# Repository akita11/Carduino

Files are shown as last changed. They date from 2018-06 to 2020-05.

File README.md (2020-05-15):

# Carduino

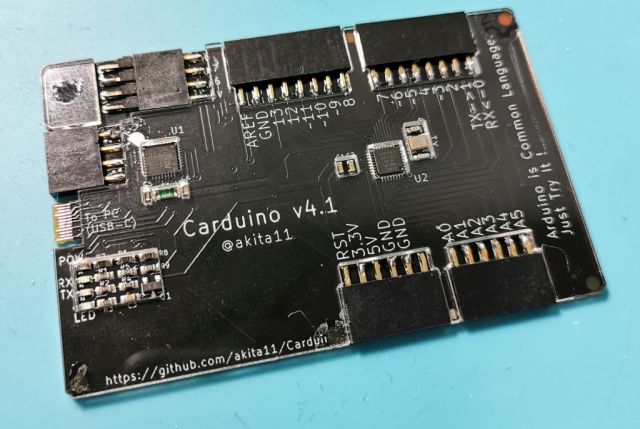
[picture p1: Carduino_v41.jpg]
omote


Carduino (v4.1)は、クレジットカードサイズ・厚さ2.4mmの、ArduinoUNO互換機です。
財布などにいつもいれておいて、いつでもその場でArduinoを使うことができます。
「Arduinoは興味あるんだけど、まだ触ったことないんだよね」という人に会ったら、その場でArduinoを体験してもらいましょう。
* ArduinoIDEの導入からLチカまでの手順は、本体裏面にシルクで書かれています。またArduinoIDEのダウンロード先もQRコードで読み取れます。
* USB-Aコネクタ（収納式）で、PCのUSB端子に直接差し込むことができます。またUSB Type-Cケーブルで接続することもできます。
* Arduinoの入出力端子はメスソケットですので、ジャンパワイヤ等をさしてつかうこともできます。
* USB-シリアル変換には、FTDI FT232Rを使っています。
* [スイッチサイエンスで委託販売はじまりました](https://www.switch-science.com/catalog/6368/)

# 使い方

本体裏面のシルクを参照してください。

PCとの接続は、以下の2通りが可能です。
* 本体のコネクタをいったんはずし、以下のようにとりつけ、PCのUSBポートに直接さしこみます。（※コネクタの向きに注意してください。収納時とは表裏を逆にさして使用します。表裏を逆で使用すると、本体やPCを破損する恐れがあります）

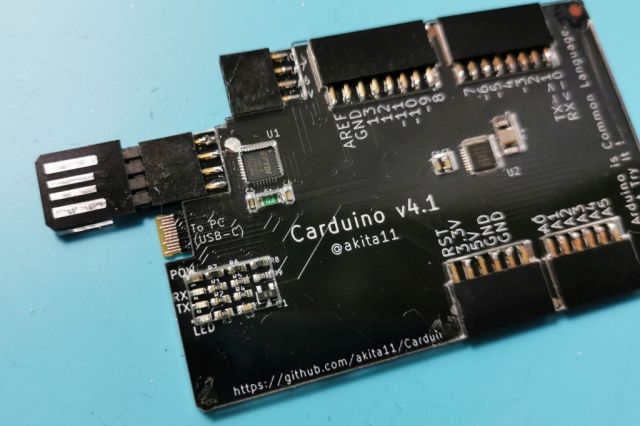
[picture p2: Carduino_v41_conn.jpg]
USB connector


* USB Type-Cケーブルを本体コネクタ部にさしこみます。

なお未使用時にUSBコネクタ部を格納しておくコネクタには、A6/A7、電源5V、GNDがつながっています。

# 作り方

* ガーバーデータ(Carduino_v41_gerber.zip)で基板製造（板厚0.6mm）し、部品表（Carduino_v41_bom.xlsx）の部品をとりつけます。
* 4p、6p、8pのピンソケット（各2個：秋月電子等で購入できます）を、基板の溝にあわせて横向けにはんだ付けします。また4pピンヘッダ（秋月電子等で購入できます）をUSBコネクタ側にとりつけます。
* 板厚1mmまたは1.5mmのアクリル板をCarduino_v41_cover.pdfでレーザーカッター等でカットし、本体に透明両面テープや透明ボンド等で固定します。
* ArduinoUNO用のブートローダを書き込みます

# 作者

Junichi Akita (akita@ifdl.jp, @akita11)

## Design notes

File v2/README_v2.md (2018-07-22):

# Carduino

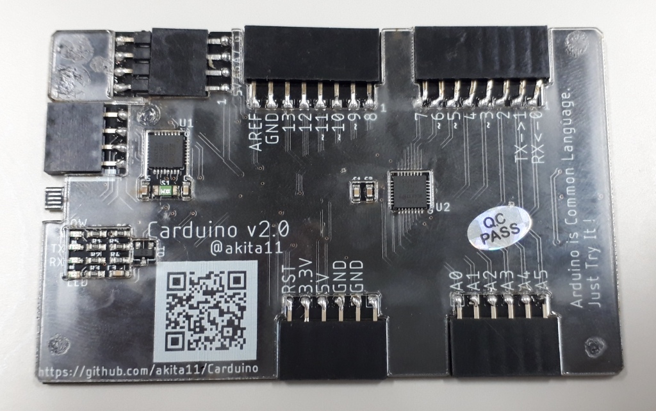
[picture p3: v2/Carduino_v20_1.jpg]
omote


Carduinoは、クレジットカードサイズ・厚さ2.4mmの、Arduino互換機(ArduinoProMini/8MHz)です。
財布などにいつもいれておいて、いつでもその場でArduinoを使うことができます。
「Arduinoは興味あるんだけど、まだ触ったことないんだよね」という人に会ったら、その場でArduinoを体験してもらいましょう。
* ArduinoIDEの導入からLチカまでの手順は、本体裏面にシルクで書かれています。またArduinoIDEのダウンロード先もQRコードで読み取れます。
* USB-Aコネクタ（収納式）で、PCのUSB端子に直接差し込むことができます。またmicroUSBケーブルで接続することもできます。
* Arduinoの入出力端子はメスソケットですので、ジャンパワイヤ等をさしてつかうこともできます。
* USB-シリアル変換には、FTDI FT232Rを使っています。
* [スイッチサイエンスで委託販売はじまりました](https://www.switch-science.com/catalog/3917/)

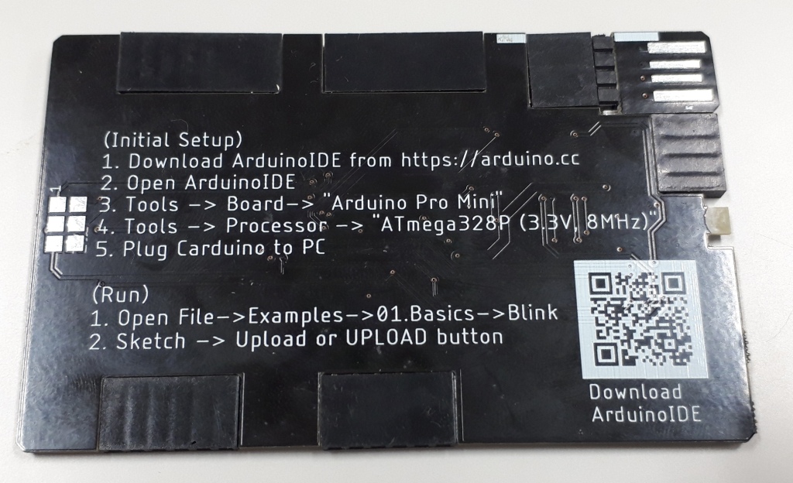
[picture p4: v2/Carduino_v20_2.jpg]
ura


# 使い方

本体裏面のシルクを参照してください。

PCとの接続は、以下の2通りが可能です。
* 本体のコネクタをいったんはずし、以下のようにとりつけ、PCのUSBポートに直接さしこみます。（※コネクタの向きに注意してください。表裏が逆の場合、本体やPCを破損する恐れがあります）
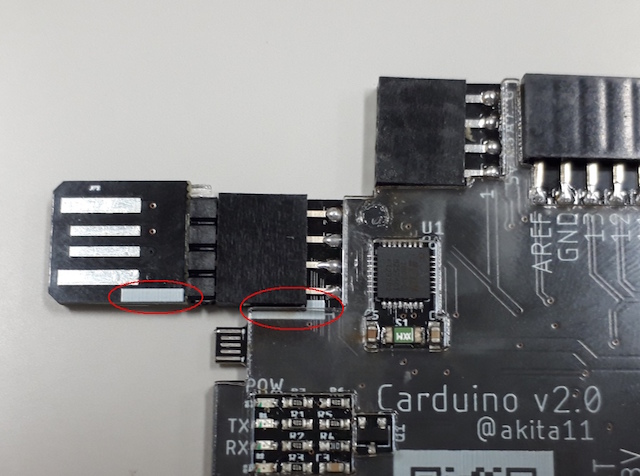
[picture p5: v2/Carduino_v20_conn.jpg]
USB connector


* microUSBケーブルを以下のように本体にさしこみます。（表裏に注意してください。基板パターンがある面が、ケーブルのmicroUSBコネクタの端子側になります） 

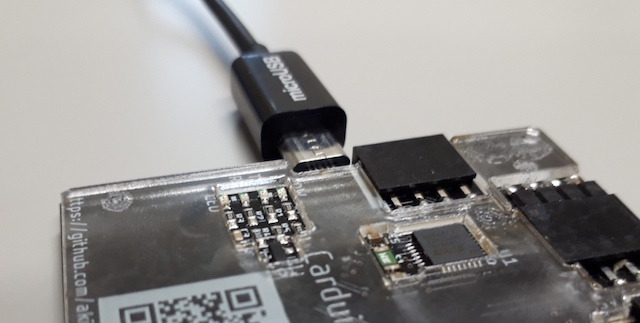
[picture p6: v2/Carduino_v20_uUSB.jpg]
microUSB connector


なお未使用時にUSBコネクタ部を格納しておくコネクタには、A6/A7、電源5V、GNDがつながっています。

# 作り方

* ガーバーデータ(Carduino_v20_gerber.zip)で基板製造（板厚1.0mm）し、BOM（部品表）の部品をとりつけます。※v20は、D0-D7のコネクタ用の基板切り書きの位置が少し間違っています。基板を少し削れば取り付け可能ですが、気になる場合は修正版ガーバーデータ(Carduino_v21_gerber.zip)を使用してください。ただし後述のレーザー加工データを少し修正する必要があります（未修正）
* 4p、6p、8pのピンソケット（各2個：秋月電子等で購入できます）を、基板の溝にあわせて横向けにはんだ付けします。また4pピンヘッダ（秋月電子等で購入できます）をUSBコネクタ側にとりつけます。
* microUSBコネクタ部を使用する場合は、コネクタ部周辺をフライス盤で、板厚0.6mmまで削ります
* 板厚1mmのアクリル板をレーザーカッター等でカットし、本体に透明両面テープや木工用ボンド等で固定します。
* ArduinoProMini(3.3V,8MHz)用のブートローダを書き込みます

# 作者

Junichi Akita (akita@ifdl.jp, @akita11)

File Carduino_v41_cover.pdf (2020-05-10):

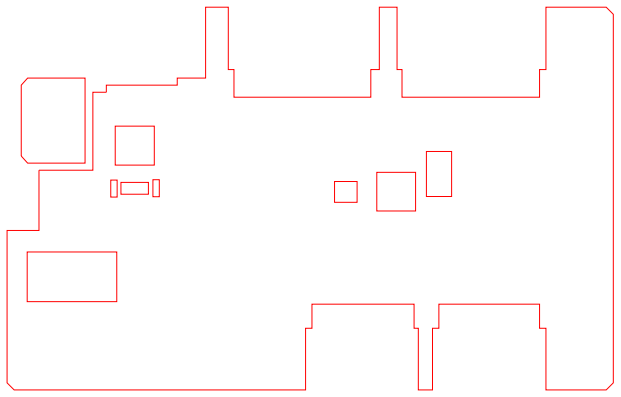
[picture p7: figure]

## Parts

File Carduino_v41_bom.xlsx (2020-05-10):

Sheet: PCB Specification
Your PCB Specification
PCB Quantity | 10pcs
Layer | 2layer
PCB Thickness | 0.6mm
Dimensions | 85.6 x 54.0mm
Castellated Hole | No
PCB Color | Black
Surface Finish | HASL Lead Free
Copper Weight | 1oz
Text Color | White
Different Design | 1
Please find more PCB information on our on-line PCB ordering Page
https://www.elecrow.com/pcb-manufacturing.html

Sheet: BOM
Carduino_v41
# | Reference | QTY | Value | Package | Manufacturer Part number | Description | SMD | THT | Original | Elecrow PN | Note
1 | C1-C4 | 4 | 0.1uF | C0603 |  | Capacitor | 8 |  | N | 2013010A
2 | C5 | 1 | 1uF | C0603 |  | Capacitor | 2 |  | N | 2013501A
3 | C6-C7 | 2 | 10pF | C0603 | 1276-2151-1-ND | Capacitor | 4 |  | N
4 | D1 | 1 | Red | D0603 |  | LED | 2 |  | N | 4040506A
5 | D2,D4 | 2 | Green | D0603 | SML-D13FWT86CT-ND | LED | 4 |  | N |  | about 20mcd, 555-565nm wavelength
6 | D3 | 1 | Yellow | D0603 | P10KGCT-ND | LED | 2 |  | N | 4040606A
7 | Q1 | 1 | CJ2302 | SOT23-3 | CJ2302 | nMOS | 3 |  | N | 4021523A
8 | R1-R3,R5-R7 | 6 | 1k | R0603 |  | Resistor | 12 |  | N | 1022501A
9 | R4 | 1 | 10k | R0603 |  | Resistor | 2 |  | N | 1023510A
10 | R8,R9 | 2 | 5.1k | R0603 |  | Resistor | 2 |  | N
11 | S1 | 1 | PolySW | P1206 |  | PolySW | 2 |  | N | 4060505A
12 | U1 | 1 | FT232RQ | QFN32 | 68-1008-1-ND | IC | 32 |  | Y
13 | U2 | 1 | ATMEGA328P-MU | QFN32 | ATMEGA328P-MUCT-ND | IC | 32 |  | Y
14 | X1 | 1 | 16MHz | X3225 | SER4069CT-ND | Crystal, 16MHz | 4
 |  |  |  |  |  | total： | 111 | 0
 | Declare：
 | 1、If the component should be original like Digi-key or Mouser，the component must have complete Manufacture part number

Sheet: Position File
Designator | Footprint | Center-X(mm) | Center-Y(mm) | Layer | Rotation
C1 | C0603 | 46.73 | 28 | TopLayer | 270
C2 | C0603 | 48.73 | 28 | TopLayer | 270
C3 | C0603 | 10.5 | 13 | TopLayer | 0
C4 | C0603 | 21 | 28.5 | TopLayer | 90
C5 | C0603 | 15 | 28.5 | TopLayer | 270
C6 | C0603 | 60.96 | 27.94 | TopLayer | 0
C7 | C0603 | 60.96 | 33.02 | TopLayer | 180
D1 | D0603 | 4 | 17 | TopLayer | 90
D2 | D0603 | 4 | 15 | TopLayer | 90
D3 | D0603 | 4 | 13 | TopLayer | 90
D4 | D0603 | 4 | 19 | TopLayer | 90
Q1 | SOT23-3 | 14 | 14 | TopLayer | 180
R1 | R0603 | 7 | 17 | TopLayer | 0
R2 | R0603 | 7 | 15 | TopLayer | 0
R3 | R0603 | 7 | 13 | TopLayer | 0
R4 | R0603 | 10.5 | 15 | TopLayer | 180
R5 | R0603 | 10.5 | 17 | TopLayer | 0
R6 | R0603 | 10.5 | 19 | TopLayer | 0
R7 | R0603 | 7 | 19 | TopLayer | 0
R8 | R0603 | 14 | 19 | TopLayer | 180
R9 | R0603 | 14 | 17 | TopLayer | 180
S1 | R1206 | 18 | 28.5 | TopLayer | 0
U1 | QFN32 | 18 | 34.5 | TopLayer | 270
U2 | QFN32 | 55 | 28 | TopLayer | 180
X1 | X3225 | 60.96 | 30.48 | TopLayer | 0

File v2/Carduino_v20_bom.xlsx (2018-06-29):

BOM for Carduino_v11
Elecrow PN | Parts | Value | Package | QTY | Digikey/Mouser/Manufacturer Part | Remark/ Link
2013010A | C1,C3,C4 | 0.1u | C0603 | 3
2013501A | C2,C5 | 1u | C0603 | 2
4040506A | D1 | Red | D0603 | 1
4040706A | D2,D4 | Green | D0603 | 2
4040606A | D3 | Yellow | D0603 | 1
4021523A | Q1 | CJ2302 | SOT23-3 | 1
1022501A | R1,R2,R3,R5,R6,R7 | 1k | R0603 | 6
1023510A | R4 | 10k | R0603 | 1
4060505A | S1 | PolySW | P1206 | 1
 | U1 | FT232RQ |  | 1 | 68-1008-1-ND | FTDI FT232R, QFN32
 | U2 | ATMEGA328P-MU |  | 1 | ATMEGA328P-MUCT-ND | Microchip ATmega328P, QFN32

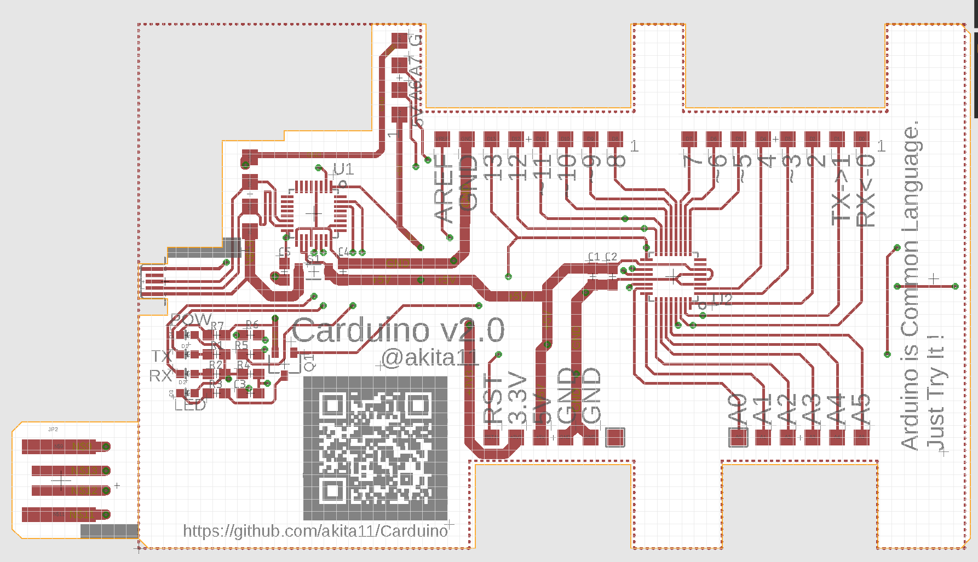
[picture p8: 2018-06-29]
v2/Carduino_v20_PartsMapping.png

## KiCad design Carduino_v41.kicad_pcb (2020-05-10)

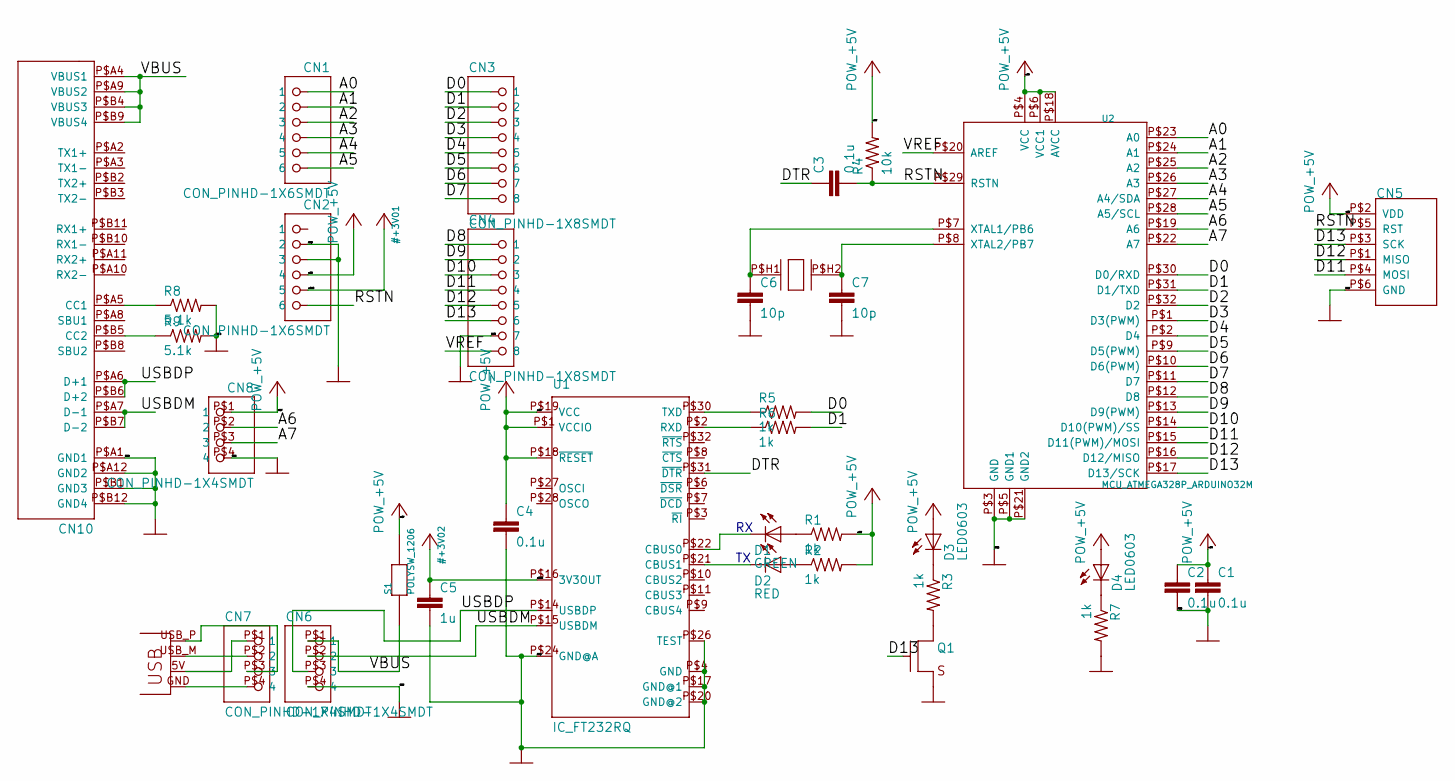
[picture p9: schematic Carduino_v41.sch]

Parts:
C1, C2, C3, C4: 0.1u; 0603
C5: 1u; 0603
C6, C7: 10p; 0603
CN1, CN2: CON_PINHD-1X6SMDT; 1X06SMD_THIN
CN3, CN4: CON_PINHD-1X8SMDT; 1X08SMD_THIN
CN5: CON_AVRISPSMD; 2X3SMD
CN6, CN7, CN8: CON_PINHD-1X4SMDT; 1X04SMD_THIN
CN10: CON_USB-CPCBPLUG; USB-C_PCBPLUG
D1: GREEN; SPARKFUN_LED-0603
D2: RED; SPARKFUN_LED-0603
D3, D4: LED0603; SPARKFUN_LED-0603
JP2: CON_USBPCB; USB-A-PCB
Q1: TR_NMOS_IRLML6344; SOT-23-3-2916
R1, R2, R3, R5, R6, R7: 1k; 0603
R4: 10k; 0603
R8, R9: 5.1k; 0603
S1: POLYSW_1206; 1206
U1: IC_FT232RQ; QFN32
U2: MCU_ATMEGA328P_ARDUINO32M; QFN32
X1: XTAL3255; XTAL_3225

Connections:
+3V3: C5.1, CN2.P$5 (5), U1.P$16 (3V3OUT)
+5V: C1.1, C2.1, C4.1, CN2.P$4 (4), CN5.P$2 (VDD), CN8.P$1 (1), D3.A, D4.A, R1.2, R2.2, R4.2, S1.P$2, U1.P$1 (VCCIO), U1.P$18 (~RESET), U1.P$19 (VCC), U2.P$4 (VCC), U2.P$6 (VCC1), U2.P$18 (AVCC)
/A0: CN1.P$1 (1), U2.P$23 (A0)
/A1: CN1.P$2 (2), U2.P$24 (A1)
/A2: CN1.P$3 (3), U2.P$25 (A2)
/A3: CN1.P$4 (4), U2.P$26 (A3)
/A4: CN1.P$5 (5), U2.P$27 (A4/SDA)
/A5: CN1.P$6 (6), U2.P$28 (A5/SCL)
/A6: CN8.P$2 (2), U2.P$19 (A6)
/A7: CN8.P$3 (3), U2.P$22 (A7)
/D0: CN3.P$1 (1), R5.2, U2.P$30 (D0/RXD)
/D1: CN3.P$2 (2), R6.2, U2.P$31 (D1/TXD)
/D2: CN3.P$3 (3), U2.P$32 (D2)
/D3: CN3.P$4 (4), U2.P$1 (D3(PWM))
/D4: CN3.P$5 (5), U2.P$2 (D4)
/D5: CN3.P$6 (6), U2.P$9 (D5(PWM))
/D6: CN3.P$7 (7), U2.P$10 (D6(PWM))
/D7: CN3.P$8 (8), U2.P$11 (D7)
/D8: CN4.P$1 (1), U2.P$12 (D8)
/D9: CN4.P$2 (2), U2.P$13 (D9(PWM))
/D10: CN4.P$3 (3), U2.P$14 (D10(PWM)/SS)
/D11: CN4.P$4 (4), CN5.P$4 (MOSI), U2.P$15 (D11(PWM)/MOSI)
/D12: CN4.P$5 (5), CN5.P$1 (MISO), U2.P$16 (D12/MISO)
/D13: CN4.P$6 (6), CN5.P$3 (SCK), Q1.1 (G), U2.P$17 (D13/SCK)
/DTR: C3.1, U1.P$31 (~DTR)
/RSTN: C3.2, CN2.P$6 (6), CN5.P$5 (RST), R4.1, U2.P$29 (RSTN)
/USBDM: CN6.P$2 (2), CN10.P$A7 (D-1), CN10.P$B7 (D-2), U1.P$15 (USBDM)
/USBDP: CN6.P$3 (3), CN10.P$A6 (D+1), CN10.P$B6 (D+2), U1.P$14 (USBDP)
/VBUS: CN6.P$1 (1), CN10.P$A4 (VBUS1), CN10.P$A9 (VBUS2), CN10.P$B4 (VBUS3), CN10.P$B9 (VBUS4), S1.P$1
/VREF: CN4.P$8 (8), U2.P$20 (AREF)
GND: C1.2, C2.2, C4.2, C5.2, C6.2, C7.2, CN2.P$2 (2), CN2.P$3 (3), CN4.P$7 (7), CN5.P$6 (GND), CN6.P$4 (4), CN8.P$4 (4), CN10.P$A1 (GND1), CN10.P$A12 (GND2), CN10.P$B1 (GND3), CN10.P$B12 (GND4), Q1.2 (S), R7.2, R8.2, R9.2, U1.P$4 (GND), U1.P$17 (GND@1), U1.P$20 (GND@2), U1.P$24 (GND@A), U1.P$26 (TEST), U2.P$3 (GND), U2.P$5 (GND1), U2.P$21 (GND2)
unnamed: C6.1, U2.P$7 (XTAL1/PB6), X1.P$H1
unnamed: C7.1, U2.P$8 (XTAL2/PB7), X1.P$H2
unnamed: CN7.P$1 (1), JP2.5V (VBUS)
unnamed: CN7.P$2 (2), JP2.USB_M (D-)
unnamed: CN7.P$3 (3), JP2.USB_P (D+)
unnamed: CN7.P$4 (4), JP2.GND
unnamed: CN10.P$A5 (CC1), R8.1
unnamed: CN10.P$B5 (CC2), R9.1
unnamed: D1.A, R1.1
unnamed: D1.C, U1.P$22 (CBUS0)
unnamed: D2.A, R2.1
unnamed: D2.C, U1.P$21 (CBUS1)
unnamed: D3.C, R3.1
unnamed: D4.C, R7.1
unnamed: Q1.3 (D), R3.2
unnamed: R5.1, U1.P$30 (TXD)
unnamed: R6.1, U1.P$2 (RXD)

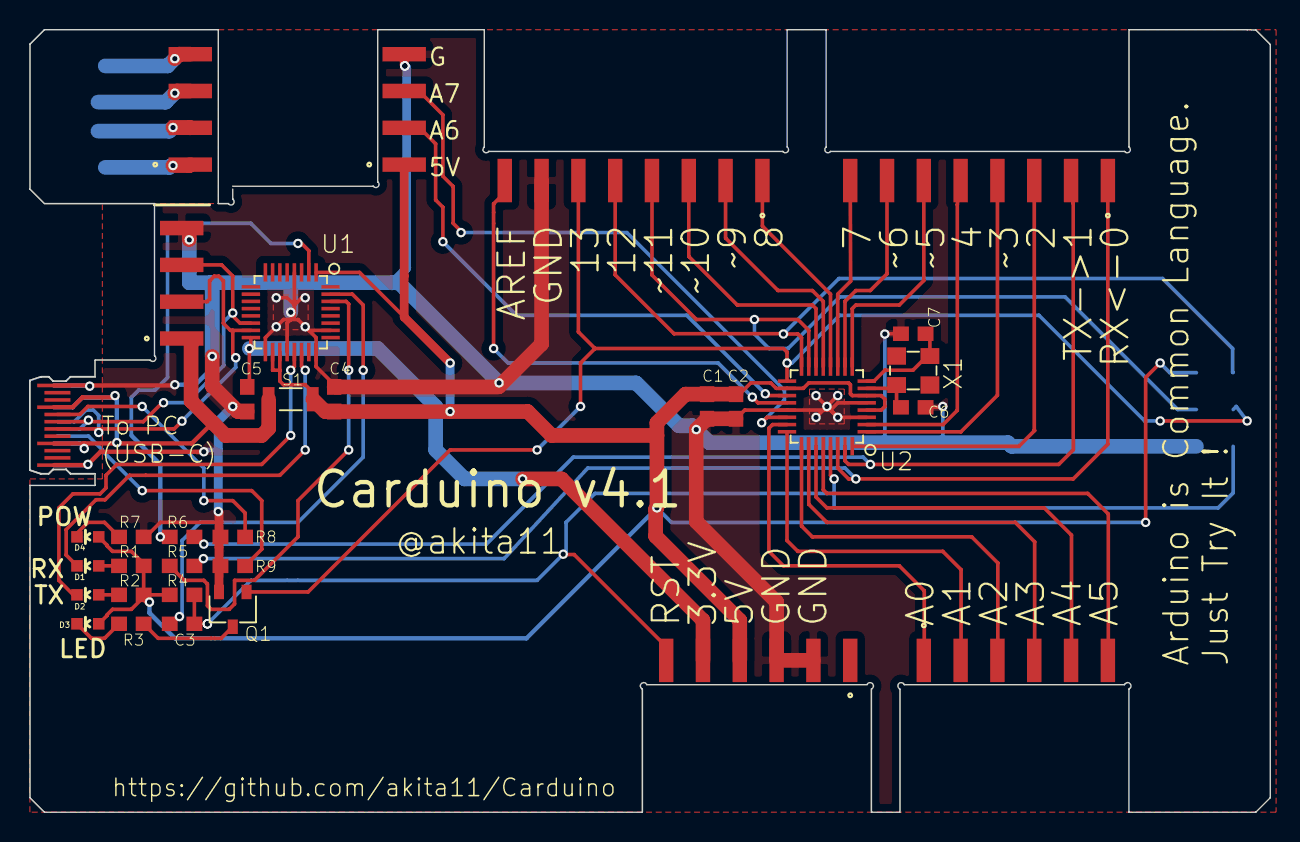
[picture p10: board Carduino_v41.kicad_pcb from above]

Board: 2 copper layers, 85.6 x 54.0 mm, 35 parts (0 on the bottom side), 48 nets.

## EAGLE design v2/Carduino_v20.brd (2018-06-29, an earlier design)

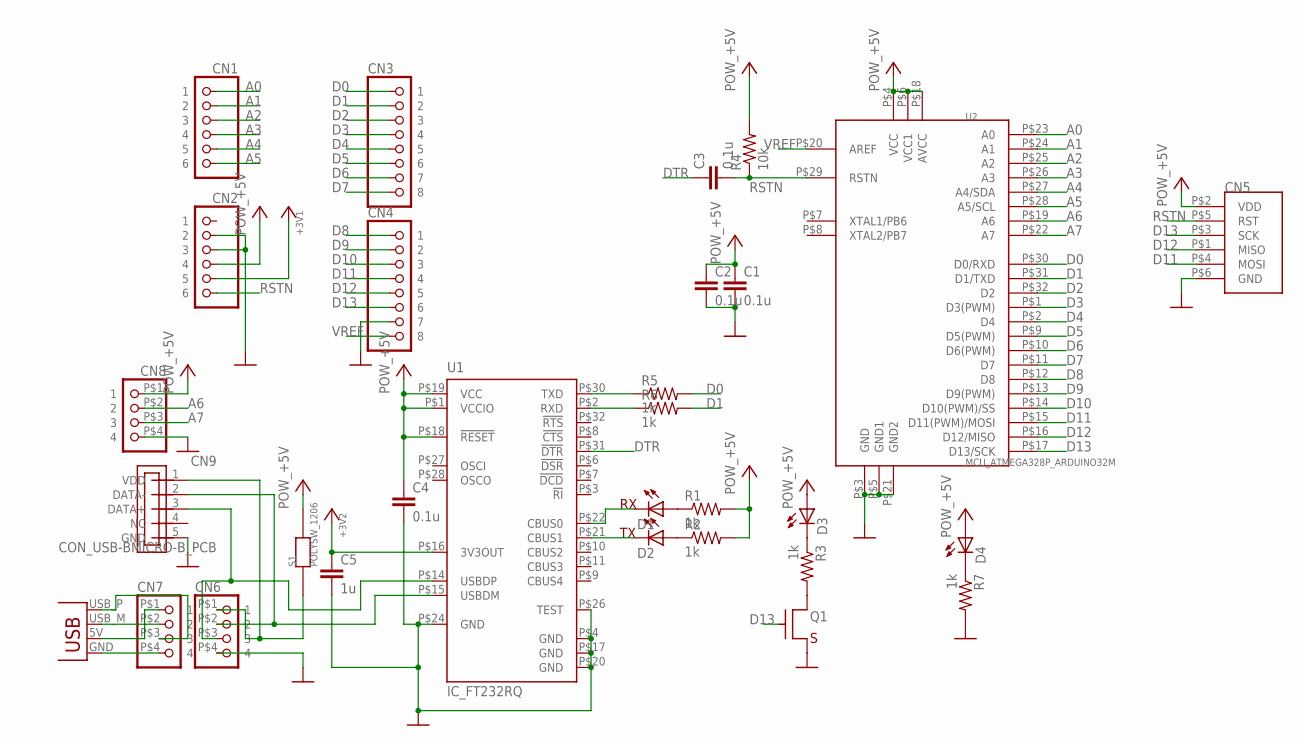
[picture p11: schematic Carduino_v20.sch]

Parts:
C1, C2, C3, C4: 0.1u; 0603
C5: 1u; 0603
CN1, CN2: CON_PINHD-1X6SMD; 1X06SMD
CN3, CN4: CON_PINHD-1X8SMD; 1X08SMD
CN5: CON_AVRISPSMD; 2X3SMD
CN6, CN7, CN8: CON_PINHD-1X4SMD; 1X04SMD
CN9: CON_USB-BMICRO-B_PCB; USB-MICRO-PCB
D1, D2, D3, D4: LED0603; SPARKFUN_LED-0603
JP2: CON_USBPCB; USB-A-PCB
Q1: TR_NMOS_IRLML6344; SOT-23-3-2916
R1, R2, R3, R5, R6, R7: 1k; 0603
R4: 10k; 0603
S1: POLYSW_1206; 1206
U1: IC_FT232RQ; QFN32
U2: MCU_ATMEGA328P_ARDUINO32M; QFN32

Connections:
+3V3: C5.1, CN2.P$5 (5), U1.P$16 (3V3OUT)
+5V: C1.1, C2.1, C4.1, CN2.P$4 (4), CN5.P$2 (VDD), CN8.P$1 (1), D3.A, D4.A, R1.2, R2.2, R4.2, S1.P$2, U1.P$1 (VCCIO), U1.P$18 (!RESET), U1.P$19 (VCC), U2.P$4 (VCC), U2.P$6 (VCC1), U2.P$18 (AVCC)
A0: CN1.P$1 (1), U2.P$23 (A0)
A1: CN1.P$2 (2), U2.P$24 (A1)
A2: CN1.P$3 (3), U2.P$25 (A2)
A3: CN1.P$4 (4), U2.P$26 (A3)
A4: CN1.P$5 (5), U2.P$27 (A4/SDA)
A5: CN1.P$6 (6), U2.P$28 (A5/SCL)
A6: CN8.P$2 (2), U2.P$19 (A6)
A7: CN8.P$3 (3), U2.P$22 (A7)
D0: CN3.P$1 (1), R5.2, U2.P$30 (D0/RXD)
D1: CN3.P$2 (2), R6.2, U2.P$31 (D1/TXD)
D2: CN3.P$3 (3), U2.P$32 (D2)
D3: CN3.P$4 (4), U2.P$1 (D3(PWM))
D4: CN3.P$5 (5), U2.P$2 (D4)
D5: CN3.P$6 (6), U2.P$9 (D5(PWM))
D6: CN3.P$7 (7), U2.P$10 (D6(PWM))
D7: CN3.P$8 (8), U2.P$11 (D7)
D8: CN4.P$1 (1), U2.P$12 (D8)
D9: CN4.P$2 (2), U2.P$13 (D9(PWM))
D10: CN4.P$3 (3), U2.P$14 (D10(PWM)/SS)
D11: CN4.P$4 (4), CN5.P$4 (MOSI), U2.P$15 (D11(PWM)/MOSI)
D12: CN4.P$5 (5), CN5.P$1 (MISO), U2.P$16 (D12/MISO)
D13: CN4.P$6 (6), CN5.P$3 (SCK), Q1.1 (G), U2.P$17 (D13/SCK)
DTR: C3.1, U1.P$31 (!DTR)
GND: C1.2, C2.2, C4.2, C5.2, CN2.P$2 (2), CN2.P$3 (3), CN4.P$7 (7), CN5.P$6 (GND), CN6.P$4 (4), CN8.P$4 (4), CN9.5 (GND), Q1.2 (S), R7.2, U1.P$4 (GND), U1.P$17 (GND), U1.P$20 (GND), U1.P$24 (GND), U1.P$26 (TEST), U2.P$3 (GND), U2.P$5 (GND1), U2.P$21 (GND2)
unnamed: D1.A, R1.1
unnamed: D2.A, R2.1
unnamed: R5.1, U1.P$30 (TXD)
unnamed: R6.1, U1.P$2 (RXD)
unnamed: D1.C, U1.P$22 (CBUS0)
unnamed: D2.C, U1.P$21 (CBUS1)
unnamed: D3.C, R3.1
unnamed: CN6.P$2 (2), CN9.2 (DATA-), U1.P$15 (USBDM)
unnamed: CN7.P$4 (4), JP2.GND
unnamed: Q1.3 (D), R3.2
unnamed: CN7.P$1 (1), JP2.5V (VBUS)
unnamed: CN7.P$2 (2), JP2.USB_M (D-)
unnamed: CN7.P$3 (3), JP2.USB_P (D+)
unnamed: D4.C, R7.1
unnamed: CN6.P$3 (3), CN9.3 (DATA+), U1.P$14 (USBDP)
unnamed: CN6.P$1 (1), CN9.1 (VDD), S1.P$1
RSTN: C3.2, CN2.P$6 (6), CN5.P$5 (RST), R4.1, U2.P$29 (RSTN)
VREF: CN4.P$8 (8), U2.P$20 (AREF)

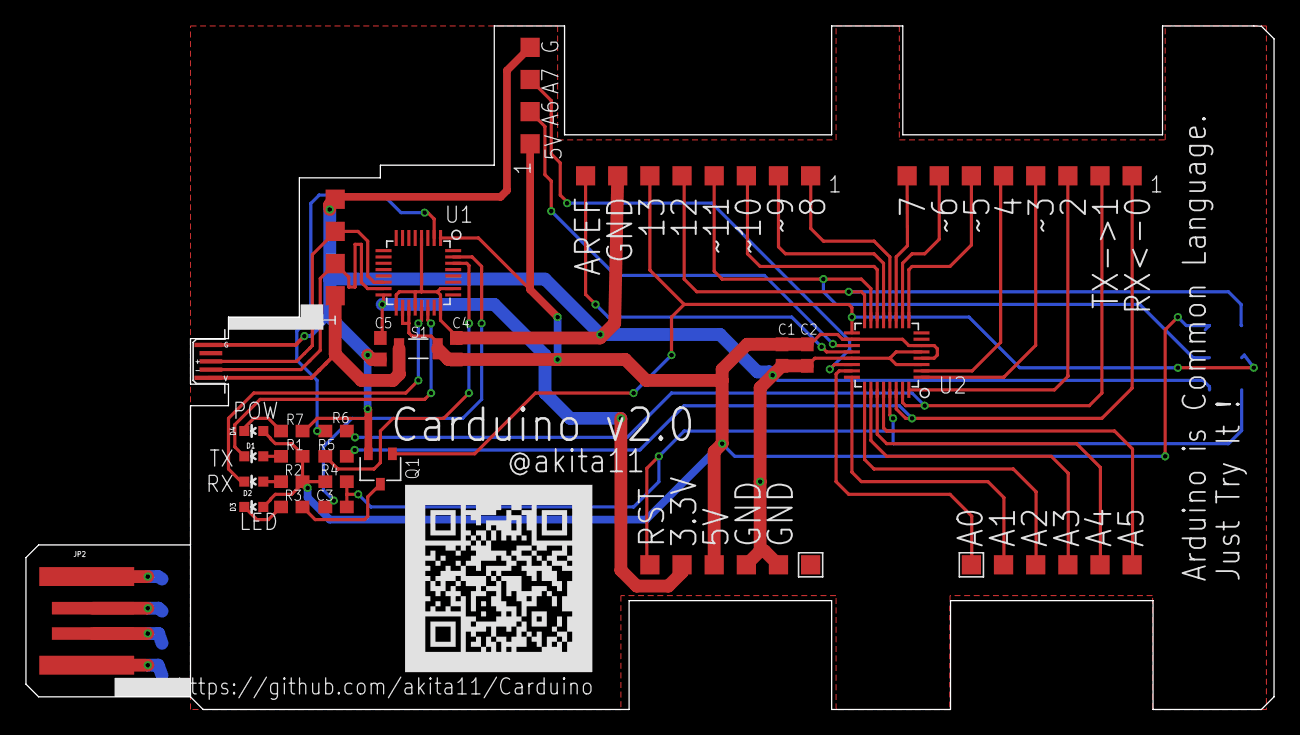
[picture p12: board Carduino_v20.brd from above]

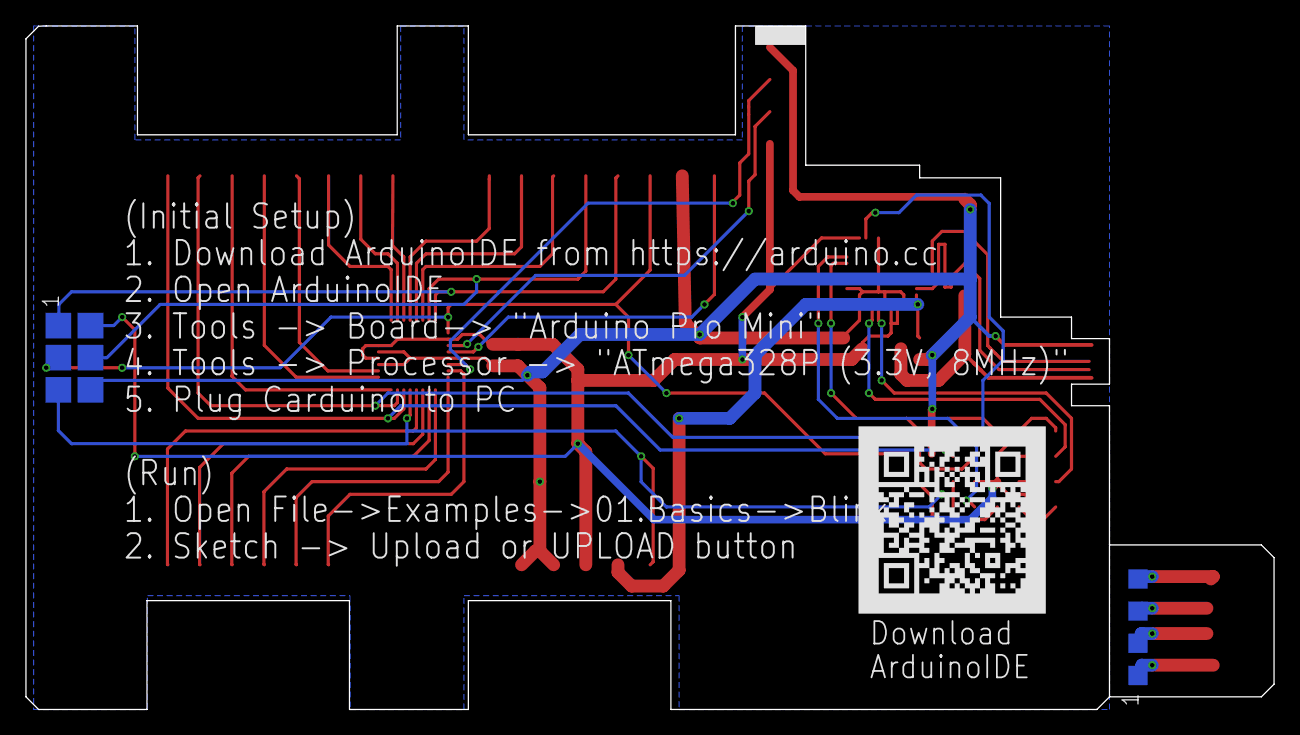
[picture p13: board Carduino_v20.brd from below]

Board: 2 copper layers, 98.6 x 54.0 mm, 30 parts (2 on the bottom side), 44 nets.

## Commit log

2018-06-29 readme.mdを修正
2018-06-29 readme.mdを整理
2018-06-29 readme.mdに画像を追加
2018-06-29 コネクタ部の写真のサイズを縮小
2018-06-29 readme.mdを整形
2018-07-01 readme.mdにA6/A7の情報を追記
2018-07-22 readme.mdに委託販売の情報を追記
2020-05-10 v41データの追加
    [Carduino_v20.brd, Carduino_v20.sch, Carduino_v20_bom.xlsx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]
2020-05-11 写真サイズの修正
2020-05-11 コネクタの表裏についての注意を追記
